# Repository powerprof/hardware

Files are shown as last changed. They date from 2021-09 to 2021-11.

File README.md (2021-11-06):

# PowerProf Hardware Resources

PowerProf is a current monitor for embedded systems. You can use it to get accurate current consumption data for any workload or operating conditions, and then use that information to design battery-based systems with just the right amount of capacity.

There are currently three supported microcontrollers - the Teensy 3.6, the LOLIN D1 Mini, and the LOLIN D32. The Teensy version supports communication over USB, the LOLIN D1 Mini supports USB and WiFi, and the LOLIN D32 supports USB, WiFi, and BLE. All boards use the [INA260 current sensor](https://www.ti.com/lit/ds/symlink/ina260.pdf) from Texas Instruments. There are two variants of the LOLIN D1 Mini board - one uses the INA260 breakout board from Adafruit, and the other uses an INA260 directly.

## Protocol Support

| Board | USB | WiFi | BLE |
| --- | --- | ---- | --- |
| Teensy  | Yes | No | No  |
| D1 Mini | Yes | Yes  | No  |
| D32 | Yes | Yes  | Yes |

## Specifications

| Name | Absolute | Typical |
| --- | --- | --- |
| Measurement Voltage | -0.3V - 40V | 0 - 36V |
| Measurement Current | 0 - 15A | 0 - 10A |
| Voltage Resolution  | 1.25mV | |
| Current Resolution  | 1.25mA | |
| Power Resolution | 10mW | |
| Sample Rate | 110Hz - 6.494kHz | 110Hz - 1kHz |
| Supply Voltage | 5V | 5V |
| Supply Current | 30-500mA | 100mA[^1] |

[^1]: Depends on which board and protocol is in use.

## Wiring Diagrams

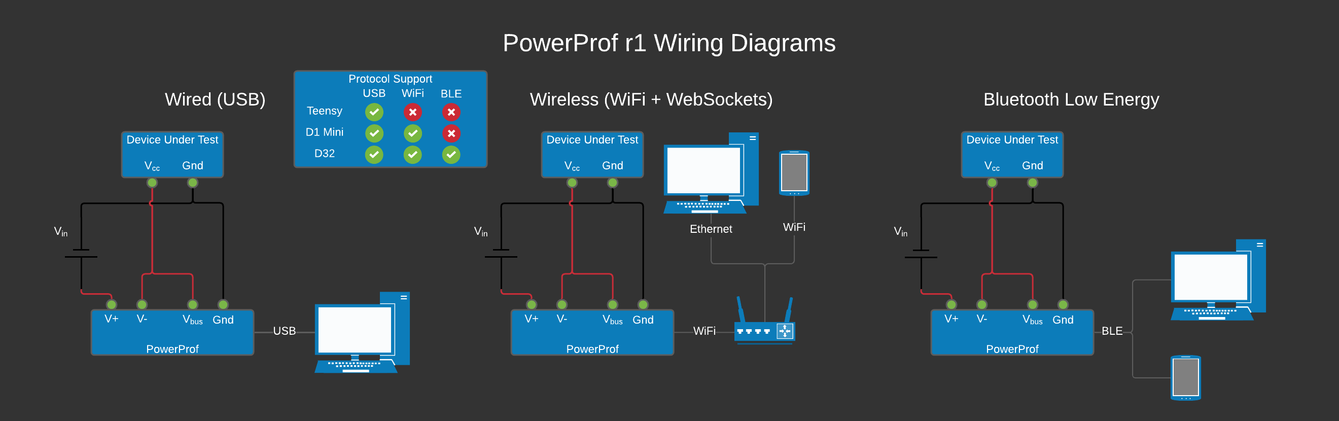
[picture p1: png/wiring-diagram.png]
wiring diagram


## Teensy

The Teensy board is a carrier board which houses the microcontroller and the INA260 current sensor.

[Order this board from OSH Park](https://oshpark.com/shared_projects/yNJN1VsL)

### Schematic

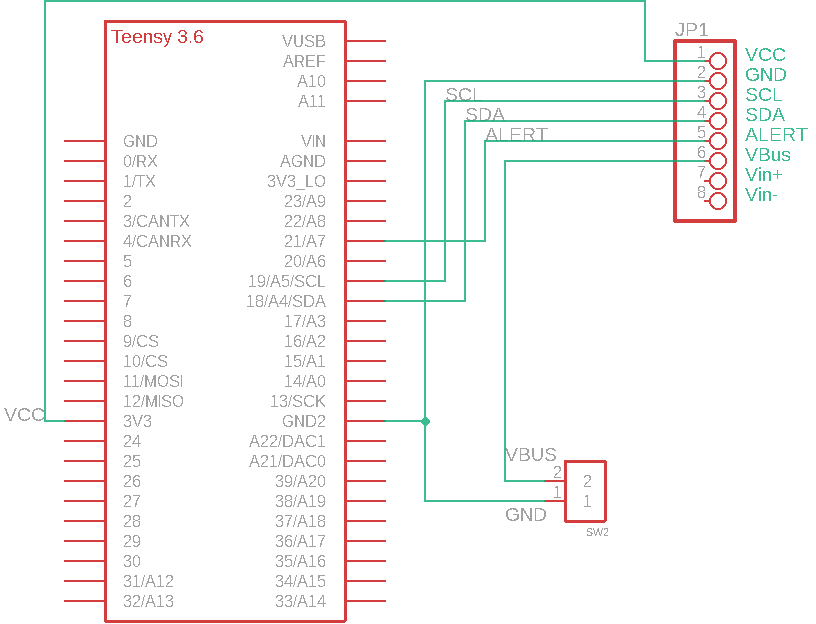
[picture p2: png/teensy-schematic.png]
teensy schematic


### Board

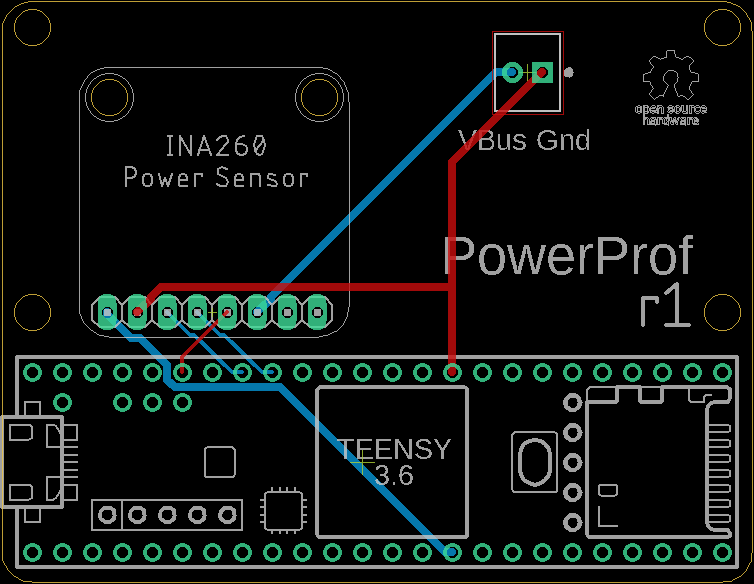
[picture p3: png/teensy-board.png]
teensy board


### BOM

| Mfg | Name | Qty | Buy |
| --- | --- | --- | --- |
| PJRC | Teensy 3.6 | 1 | [Link](https://www.pjrc.com/store/teensy36.html) |
| Adafruit | INA260 Breakout | 1 | [Link](https://www.mouser.com/ProductDetail/Adafruit/4226?qs=PzGy0jfpSMvb8foRR1BpJA%3D%3D) |
| TE Conn. | 282834-2 | 1 | [Link](https://www.mouser.com/ProductDetail/TE-Connectivity/282834-2?qs=A%252Bip%252BNCYi6N8cVKuk8xDog%3D%3D) |
| DuPont | 8-pin 2.54mm Header | 1 | |

### Assembly

1. Solder the Teensy to the top side of the board.
2. Solder the 8-pin header to the top side of the board.
3. Solder the INA260 to the 8-pin header.
4. Solder the terminal block to the top side of the board.

## LOLIN D1 Mini

### r1 - INA260 Breakout

This board is a "shield" for the D1 Mini which has an INA260 breakout board mounted on it.

[Order this board from OSH Park](https://oshpark.com/shared_projects/ZZhTuBfp)

#### Schematic

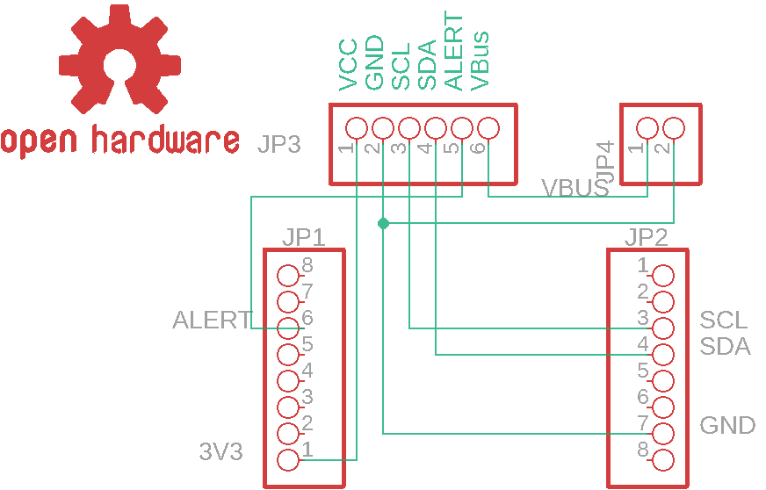
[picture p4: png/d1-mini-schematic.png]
d1 mini schematic


#### Board

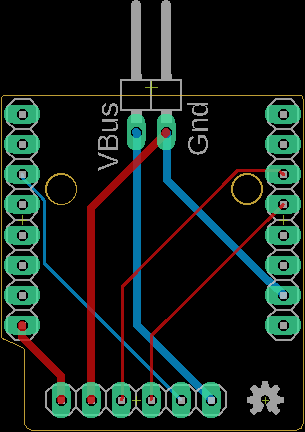
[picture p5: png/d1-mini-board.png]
d1 mini board


#### BOM

| Mfg | Name | Qty | Buy |
| --- | --- | --- | --- |
| LOLIN | D1 Mini | 1 | [Link](https://www.wemos.cc/en/latest/d1/d1_mini.html) |
| Adafruit | INA260 Breakout | 1 | [Link](https://www.mouser.com/ProductDetail/Adafruit/4226?qs=PzGy0jfpSMvb8foRR1BpJA%3D%3D) |
| DuPont | 8-pin 2.54mm Header | 2 | |
| DuPont | 6-pin 2.54mm Header | 1 | |
| DuPont | 2-pin Right Angle 2.54mm Header | 1 | |

#### Assembly

1. Solder the two 8-pin headers on the underside of the board.
2. Solder the 6-pin header to the top side of the board.
3. Solder the 2-pin right angle header to the top side of the board.
4. Solder the INA260 to the 6-pin header - make sure that V+/V- pins of the INA260 breakout are not connected!
5. Install the shield on top of a D1 Mini.

### r2 - INA260 Onboard

This board is a "shield" for the D1 Mini which has an INA260 directly soldered to it.

[Order this board from OSH Park](https://oshpark.com/shared_projects/TSTmxFWv)

#### Schematic

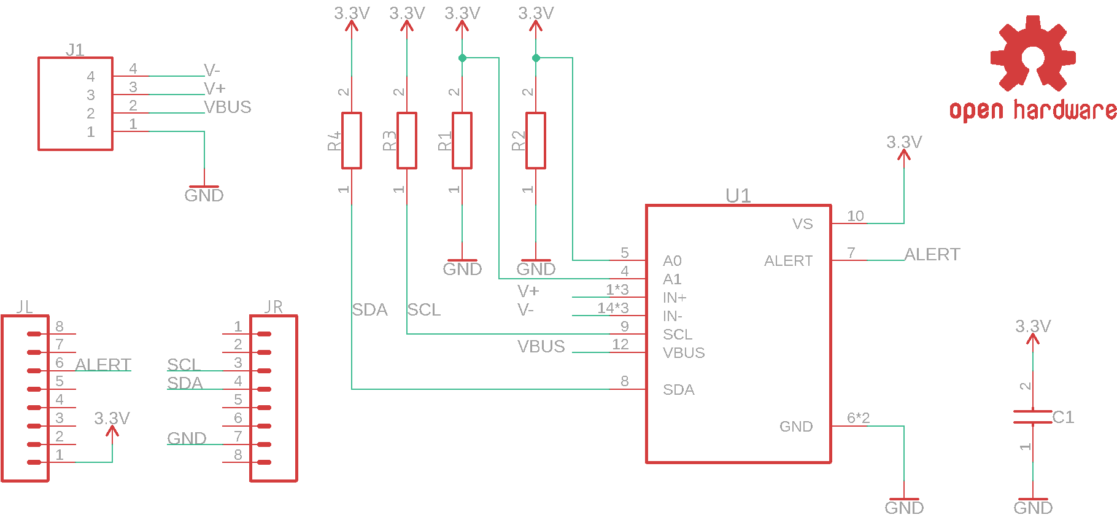
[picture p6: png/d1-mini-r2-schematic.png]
d1 mini schematic


#### Board

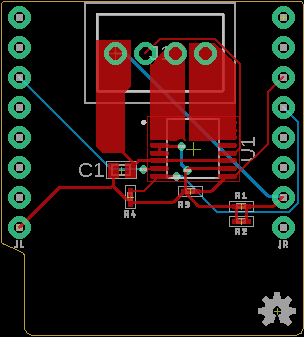
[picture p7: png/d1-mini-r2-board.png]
d1 mini board


#### BOM

| Mfg | Name | Qty | Buy |
| --- | --- | --- | --- |
| LOLIN | D1 Mini | 1 | [Link](https://www.wemos.cc/en/latest/d1/d1_mini.html) |
| Adafruit | INA260 Breakout | 1 | [Link](https://www.mouser.com/ProductDetail/Adafruit/4226?qs=PzGy0jfpSMvb8foRR1BpJA%3D%3D) |
| DuPont | 8-pin 2.54mm Header | 2 | |
| TI | INA260AIPWR | 1 | [Link](https://www.mouser.com/ProductDetail/595-INA260AIPWR) |
| Bourns | CR0201AFW-1002GAS | 4 | [Link](https://www.mouser.com/ProductDetail/652-CR0201AFW1002GAS) |
| Samsung  | CL03A105MQ3CSNH | 1 | [Link](https://www.mouser.com/ProductDetail/187-CL03A105MQ3CSNH) |

#### Assembly

1. Solder the INA260 and the SMD resistors/capacitor to the top side of the board.
2. Solder the two 8-pin headers to the underside of the board.
3. Solder the 4-pin terminal block to the top side of the board.
4. Install the shield on top of a D1 Mini.

## LOLIN D32

This is a carrier board which houses the microcontroller and the INA260 current sensor.

[Order this board from OSH Park](https://oshpark.com/shared_projects/jJYH4pyw)

### Schematic

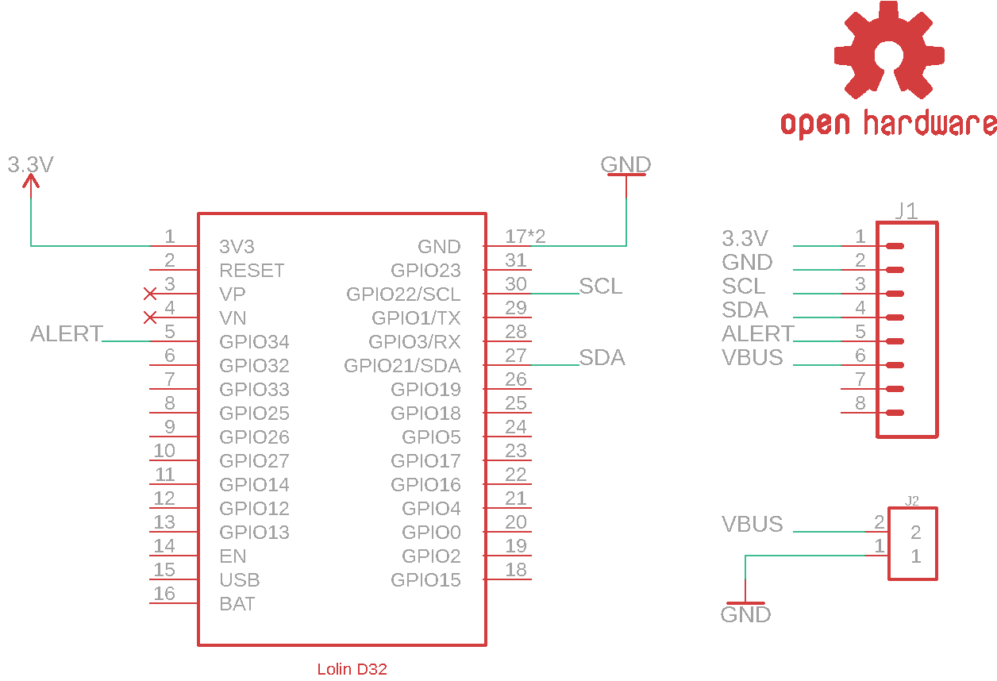
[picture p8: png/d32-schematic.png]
d32 schematic


### Board

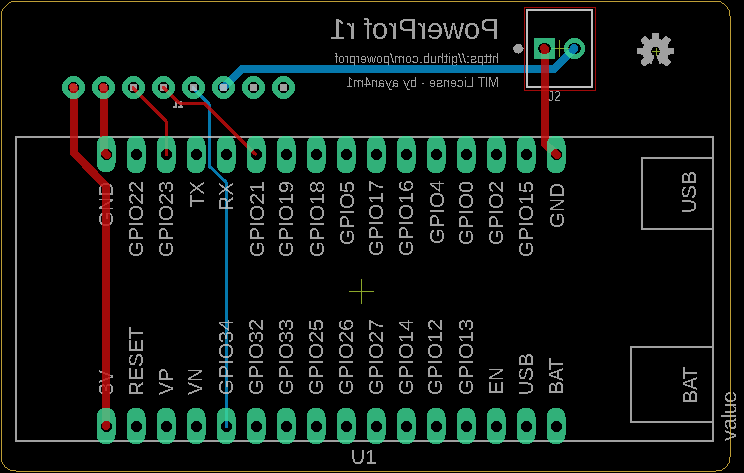
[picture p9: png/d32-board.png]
d32 board


### BOM

| Mfg | Name | Qty | Buy |
| --- | --- | --- | --- |
| LOLIN | D32 | 1 | [Link](https://www.aliexpress.com/item/32808551116.html) |
| Adafruit | INA260 Breakout | 1 | [Link](https://www.mouser.com/ProductDetail/Adafruit/4226?qs=PzGy0jfpSMvb8foRR1BpJA%3D%3D) |
| TE Conn. | 282834-2 | 1 | [Link](https://www.mouser.com/ProductDetail/TE-Connectivity/282834-2?qs=A%252Bip%252BNCYi6N8cVKuk8xDog%3D%3D) |
| DuPont | 8-pin 2.54mm Header | 1 | |

### Assembly

1. Solder the D32 to the top side of the board.
2. Solder the 8-pin header to the top side of the board.
3. Solder the INA260 breakout to the 8-pin header.
4. Solder the 2-pin terminal block to the top side of the board.

## Roadmap

Some things we'd like to add, given the time:

- One modular connector for the front-end instead of four separate wires

## Acknowledgements

Special thanks to [weeding-nerdy](https://github.com/weeding-nerdy) for their [gufu_gud](https://github.com/weeding-nerdy/gufu_gud), which was the inspiration for this project.

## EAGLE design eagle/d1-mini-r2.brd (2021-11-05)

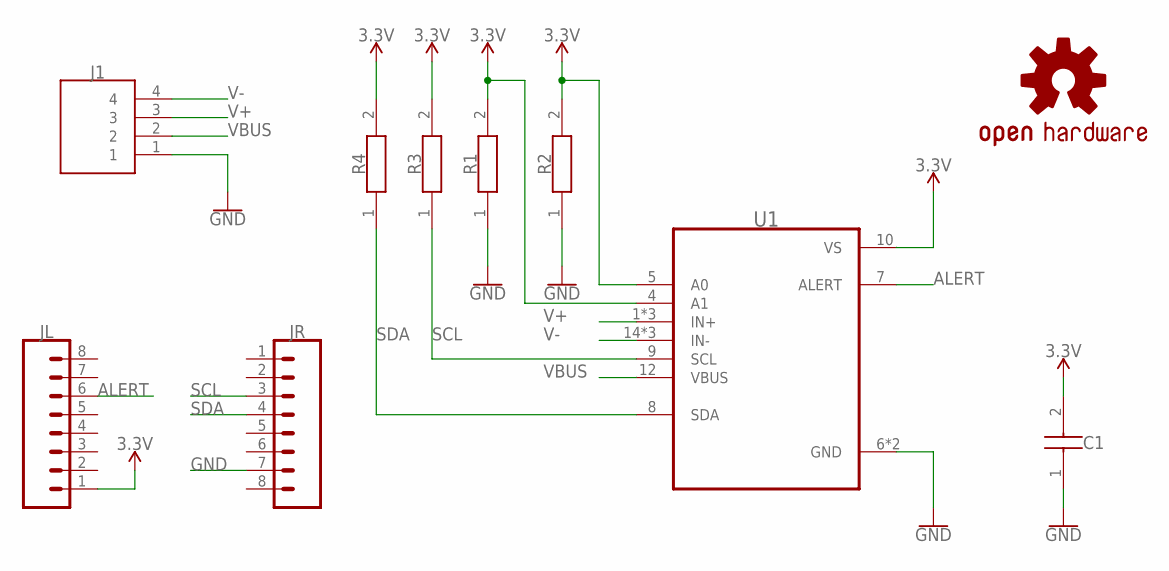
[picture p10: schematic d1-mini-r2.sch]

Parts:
C1: CL03A105MQ3CSNH; CAPC1608X80N
J1: 282834-4; 2828344
JL: CONN_08NO_SILK_FEMALE_PTH; 1X08_NO_SILK
JR: CONN_08NO_SILK_FEMALE_PTH; 1X08_NO_SILK
LOGO1: OSHW-LOGOS; OSHW-LOGO-S
R1, R2, R3, R4: CRCW020110K0FNED; RESC0603X28N
U1: INA260AIPWR; SOP65P640X120-16N

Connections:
3.3V: C1.2, JL.1, R1.2, R2.2, R3.2, R4.2, U1.4 (A1), U1.5 (A0), U1.10 (VS)
ALERT: JL.6, U1.7 (ALERT)
GND: C1.1, J1.1, JR.7, R1.1, R2.1, U1.6 (GND), U1.11 (GND)
SCL: JR.3, R3.1, U1.9 (SCL)
SDA: JR.4, R4.1, U1.8 (SDA)
V+: J1.3, U1.1 (IN+), U1.2 (IN+), U1.3 (IN+)
V-: J1.4, U1.14 (IN-), U1.15 (IN-), U1.16 (IN-)
VBUS: J1.2, U1.12 (VBUS)

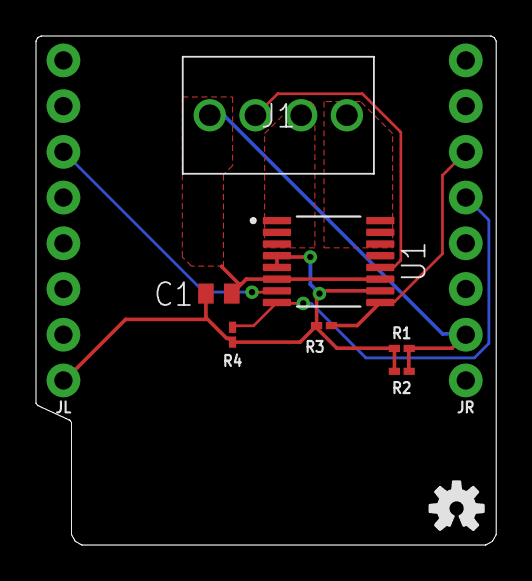
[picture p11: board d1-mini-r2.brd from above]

Board: 2 copper layers, 25.6 x 28.3 mm, 10 parts (0 on the bottom side), 8 nets.

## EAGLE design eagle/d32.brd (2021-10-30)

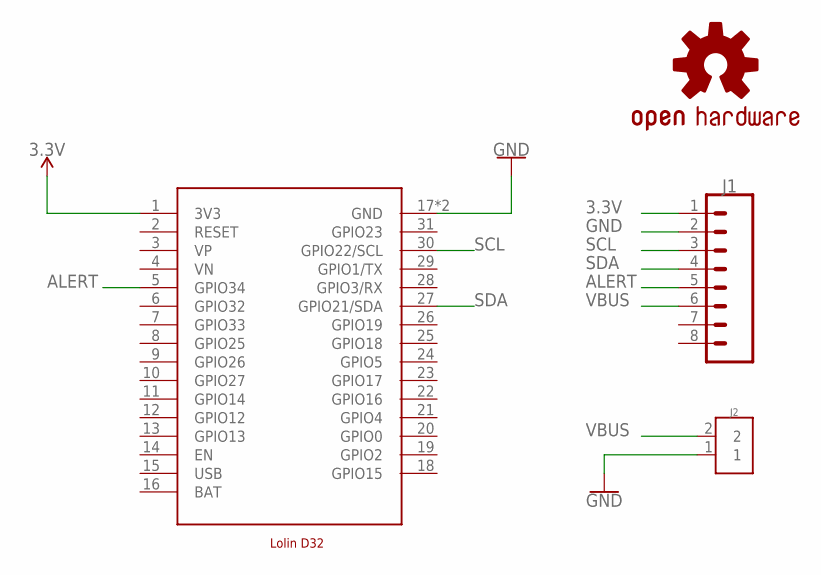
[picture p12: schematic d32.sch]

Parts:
J1: CONN_08NO_SILK_FEMALE_PTH; 1X08_NO_SILK
J2: 282834-2; CONN_282834-2
LOGO1: OSHW-LOGOS; OSHW-LOGO-S
U1: LOLIND32

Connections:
3.3V: J1.1, U1.1 (3V3)
ALERT: J1.5, U1.5 (GPIO34)
BAT: U1.16 (BAT)
GND: J1.2, J2.1, U1.17 (GND), U1.32 (GND)
SCL: J1.3, U1.30 (GPIO22/SCL)
SDA: J1.4, U1.27 (GPIO21/SDA)
USB: U1.15 (USB)
VBUS: J1.6, J2.2

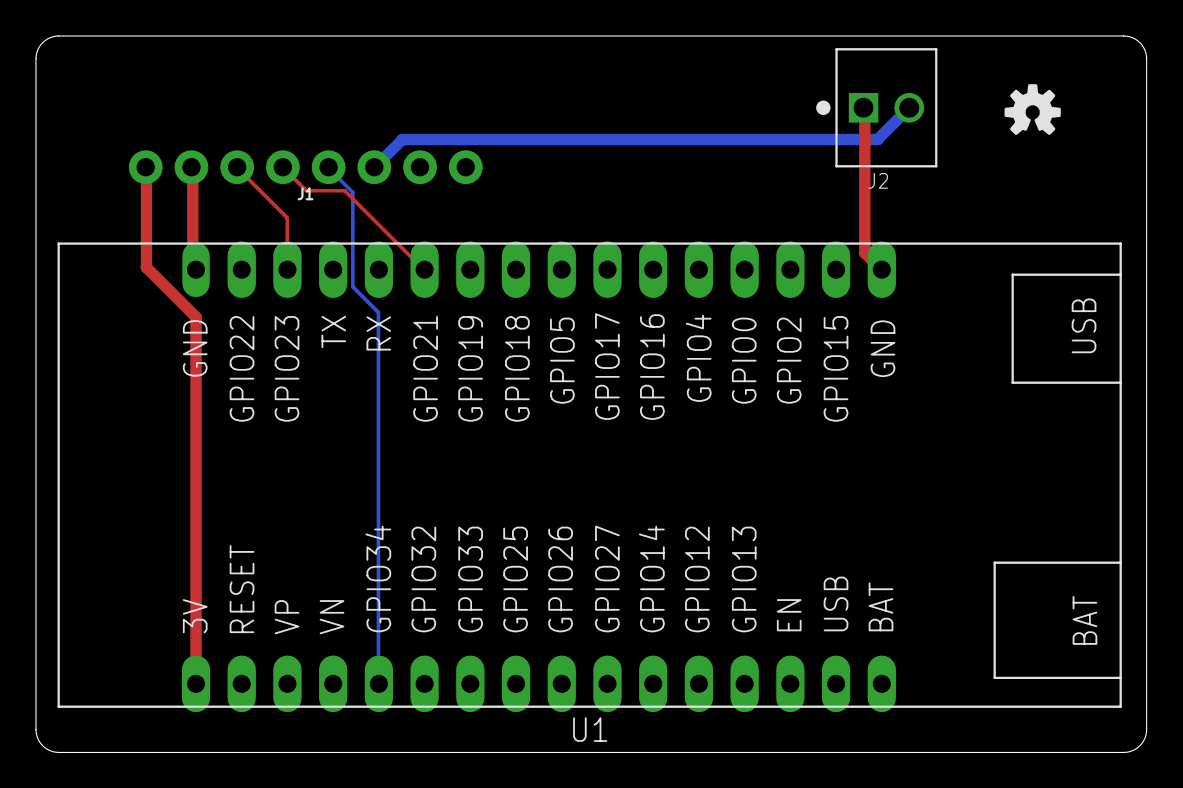
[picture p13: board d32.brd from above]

Board: 2 copper layers, 61.7 x 39.8 mm, 4 parts (0 on the bottom side), 6 nets.

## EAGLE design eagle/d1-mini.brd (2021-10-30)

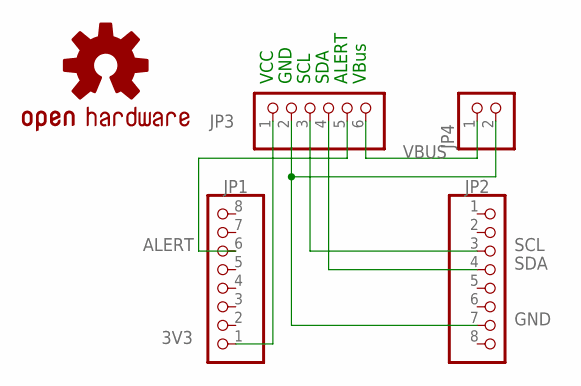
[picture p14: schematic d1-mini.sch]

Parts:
JP1, JP2: PINHD-1X8; 1X08
JP3: PINHD-1X6; 1X06
JP4: PINHD-1X2/90; 1X02/90
LOGO1: OSHW-LOGOS; OSHW-LOGO-S

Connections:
3V3: JP1.1, JP3.1
ALERT: JP1.6, JP3.5
GND: JP2.7, JP3.2, JP4.2
SCL: JP2.3, JP3.3
SDA: JP2.4, JP3.4
VBUS: JP3.6, JP4.1

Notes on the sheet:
VCC
GND
SCL
SDA
ALERT
VBus

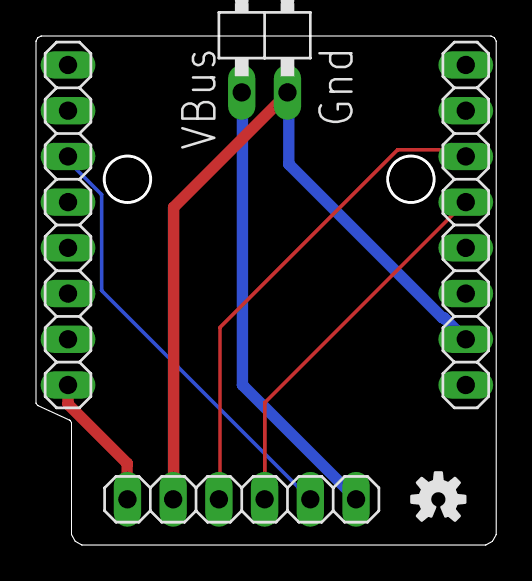
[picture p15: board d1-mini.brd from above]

Board: 2 copper layers, 25.6 x 28.3 mm, 5 parts (0 on the bottom side), 6 nets.

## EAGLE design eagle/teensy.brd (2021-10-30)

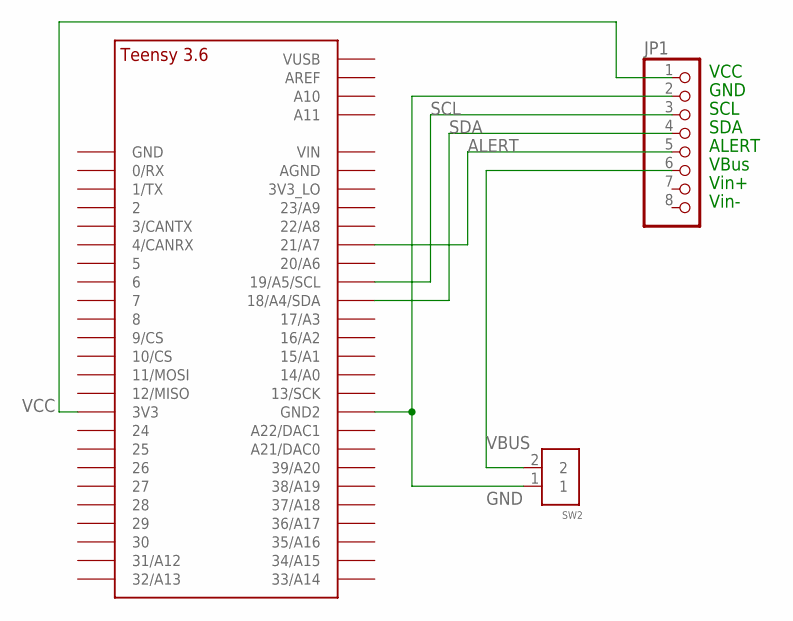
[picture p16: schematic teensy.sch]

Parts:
JP1: PINHD-1X8; 1X08
SW2: 282834-2; CONN_282834-2
U1: TEENSY_3.5/3.6_BASIC

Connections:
ALERT: JP1.5, U1.21/A7
GND: JP1.2, SW2.1, U1.GND2
SCL: JP1.3, U1.19/A5/SCL
SDA: JP1.4, U1.18/A4/SDA
VBUS: JP1.6, SW2.2
VCC: JP1.1, U1.3V3

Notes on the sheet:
VCC
GND
SCL
SDA
ALERT
VBus
Vin+
Vin-

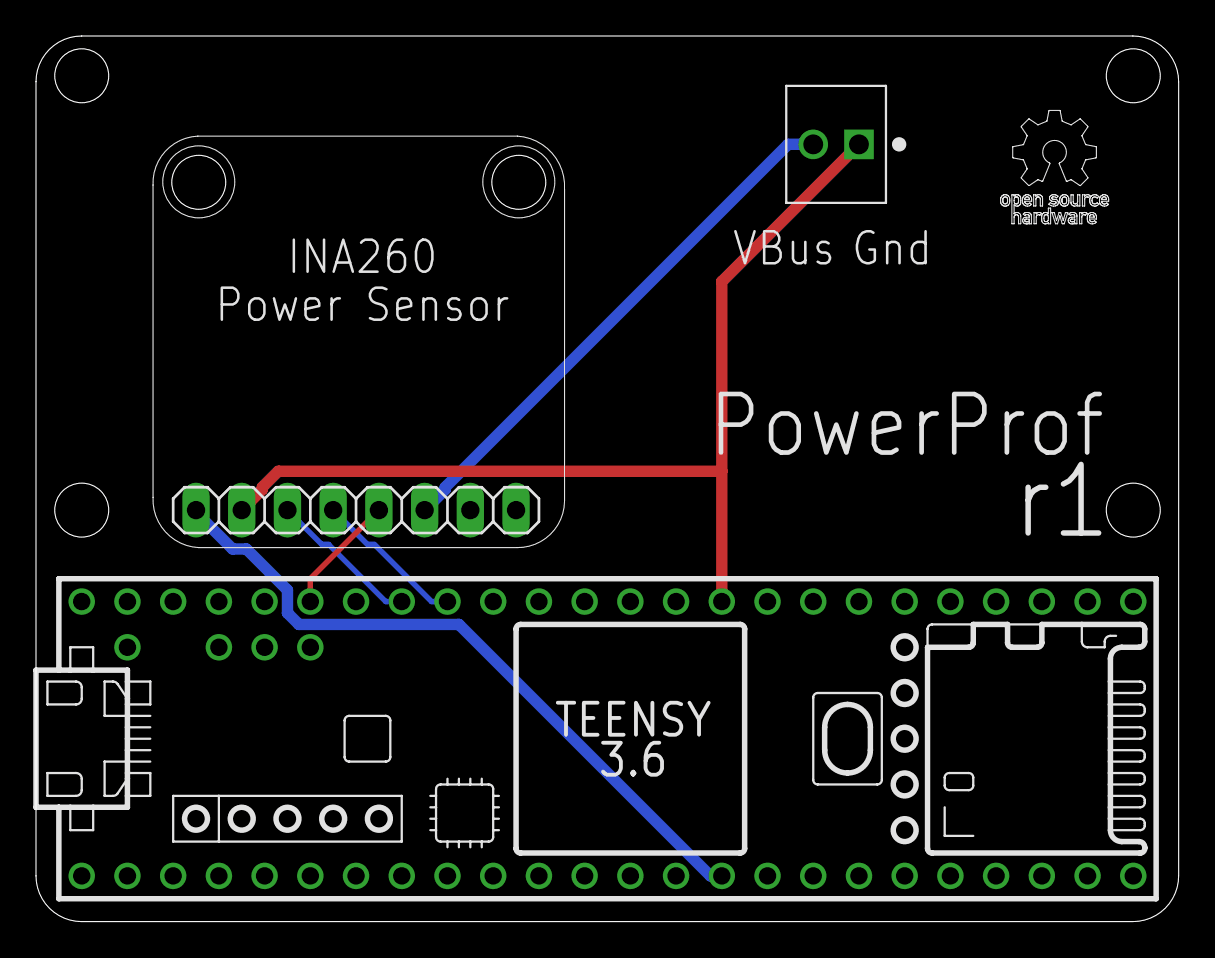
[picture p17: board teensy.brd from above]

Board: 2 copper layers, 63.5 x 49.2 mm, 3 parts (0 on the bottom side), 6 nets.

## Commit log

2021-09-13 add documentation and EAGLE files for teensy and d1 mini boards
    [d1-mini.brd, d1-mini.sch, teensy.brd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]
2021-09-14 switch d1-mini eagle board to use 2.54mm pin header for vbus/gnd and add text/oshw logo
    [d1-mini.brd, d1-mini.sch]
2021-09-17 update D1 mini board image, add wiring diagrams, expand README.md
2021-09-17 add eagle libraries for Teensy board
2021-09-18 update and sync all schematics and images - fix labels and add consistent attribution
    [d1-mini.brd, teensy.brd, teensy.sch]
2021-09-18 add specifications and assembly instructions to README.md
2021-10-01 add eagle files for D1 mini "onboard" variant
    [d1-mini-onboard.brd, d1-mini-onboard.sch]
2021-10-01 clarify that we are talking about board side
2021-10-05 add footnote about typical current
2021-10-05 update wiring diagram for BLE
2021-10-06 add top/bottom layers to board images
2021-10-06 add d32 board/schematic/bom/assembly to README.md
2021-10-17 update OSH Park link for Teensy board
2021-10-30 update clearances to 8mil (thanks tech-tx!)
    [d1-mini.brd, teensy.brd]
2021-10-30 add d32 board
    [d32.brd, d32.sch]
2021-10-30 remove broken d1-mini-onboard
    [d1-mini-onboard.brd, d1-mini-onboard.sch]
2021-10-30 sync boards to use same net classes, update images with new traces
    [d1-mini.brd, d32.brd, teensy.brd]
2021-11-05 re-add d1-mini-r2
    [d1-mini-r2.brd, d1-mini-r2.sch]
2021-11-06 update BOM with new cap/res

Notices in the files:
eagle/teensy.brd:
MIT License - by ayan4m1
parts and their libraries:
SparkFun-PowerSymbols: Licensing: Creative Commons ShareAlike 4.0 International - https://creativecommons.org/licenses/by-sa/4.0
